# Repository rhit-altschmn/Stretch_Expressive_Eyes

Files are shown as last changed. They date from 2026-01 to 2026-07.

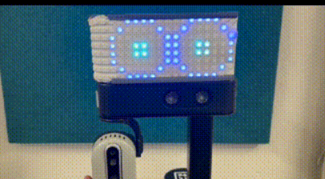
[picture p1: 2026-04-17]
Expressive_Eyes/normal eyes pic.png

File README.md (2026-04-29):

This is a custom LED eye module design for the Hello-Robo RE2. This Eye module displays different emotions (sad, angry, happy, confuse, and normal (staring)) and can gaze utilizing the tilt-pan camera located on the robot. 

Eyes_expressions gaze1-3

Eyes_expressions-3

**BOM** 

Arduino Mega or an ESP32 board

Ability to 3D print (stand)

BTF-Lighting (8cm*32cm) LED strip (link: https://a.co/d/6l0Y1tK)

**LED strip wire connections** 

Red = Vout (5V)

White = Ground 

Green = signal[data] (Pin4 in Arduino)

**How to install** 
Clone the repo into your Catkin folder.

**How to run**

1) activate the conda environment
{conda activate pickup}

2) run the Hello-Robot calibration code {stretch_robot_home.py} Remember to remove the clip!

3) Run the launch file  # If you do not need an interface comment it out in the launch file!
{roslaunch Expressive_Eyes expression.launch or roslaunch new_expressive_eyes expression.launch}

4) In a new terminal window run the serial communication (allows you to collect information from the USB port)
{rosrun rosserial_python serial_node.py /dev/ttyACM2}

*Disclaimer: The /dev/ttyACM2 corresponds to the USB port the Arduino was connected to. It might be different for you. If it does not work run **dmesg | grep tty** to figure out the TTY device *

Remember to put the clip back on before shutdown!!

**Controls**

Gaze system: 
At this stage, the Arduino should be gathering information from the camera motor. This means that as long as the code is running, the eyes will follow whenever the camera tilts or pans.

Expressions: 
Includes four expressions and a baseline mode (normal stare). To activate an expression, simply press the corresponding key.

[{H: Happy}, {O: Normal}, {N: Angry}, {B: Sad}, {C: Confused}]

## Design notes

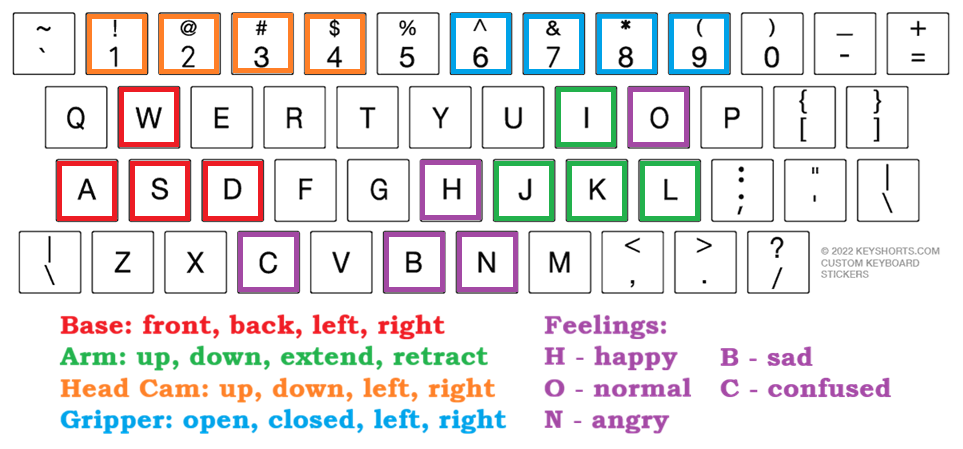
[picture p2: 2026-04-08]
Expressive_Eyes/scripts/keyboard_diagram.png

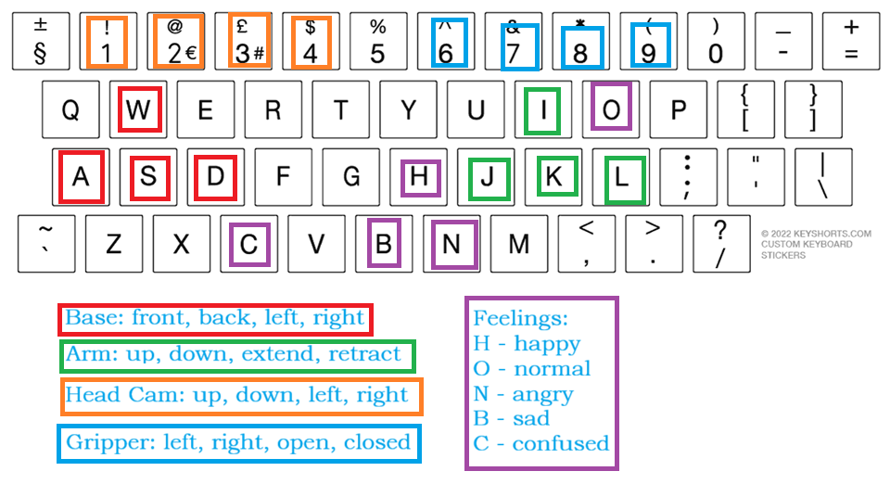
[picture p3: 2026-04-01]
Expressive_Eyes/scripts/keyboard_layout.png

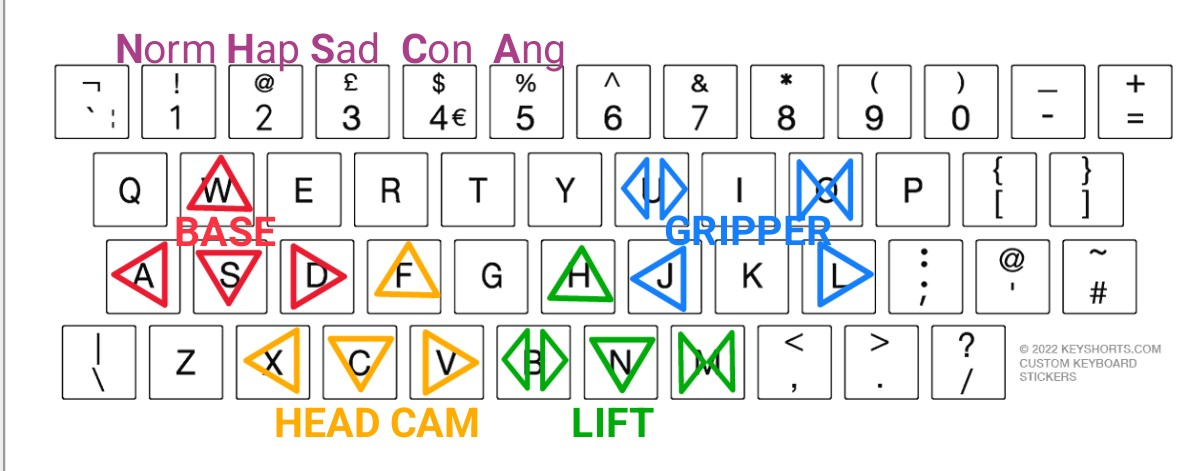
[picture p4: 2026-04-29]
Expressive_Eyes/scripts/new_keyboard_layout.png

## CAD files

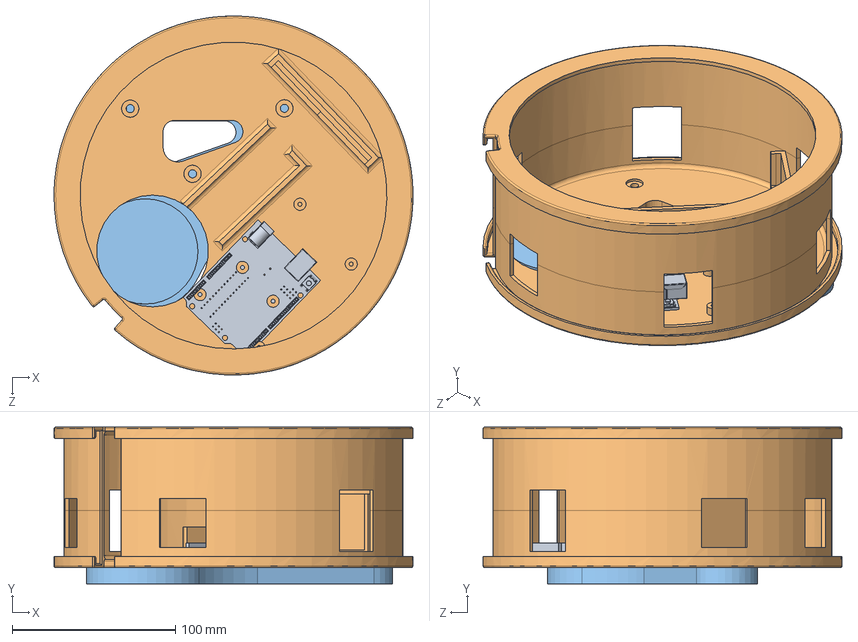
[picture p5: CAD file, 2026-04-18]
Eye_Module Stand/new_test_assembly.SLDASM
220.0 x 96.2 x 220.0 mm
Stretch_top
eye_tube_360
arduino uno

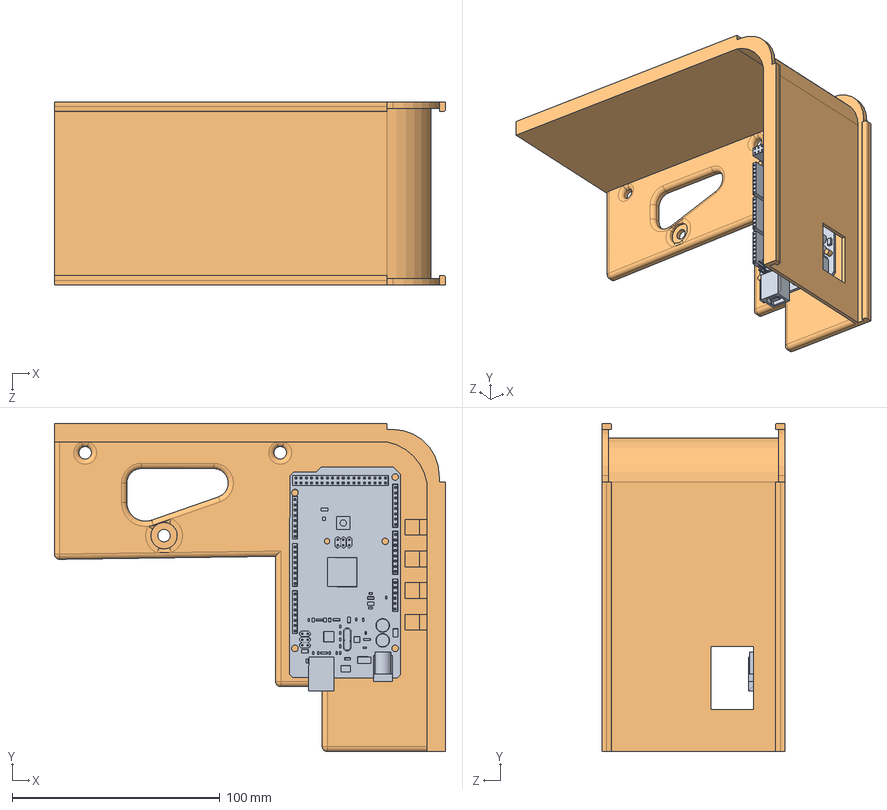
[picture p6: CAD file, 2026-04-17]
Eye_Module Stand/eyes_assem.SLDASM
188.4 x 158.2 x 88.1 mm
eye_holder (2)
ArduinoMega

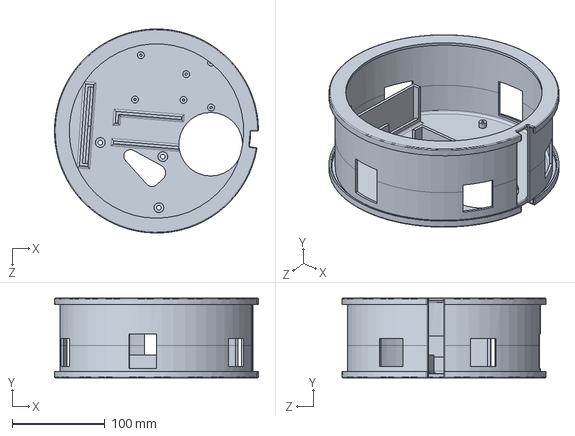
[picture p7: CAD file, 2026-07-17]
Eye_Module Stand/eye_tube_360.SLDPRT
220.0 x 86.2 x 220.0 mm

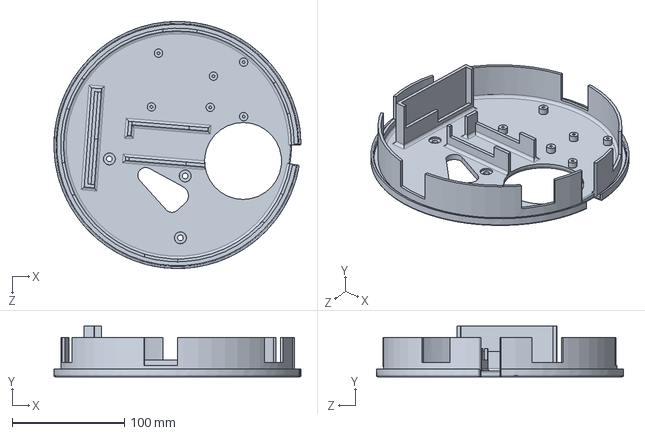
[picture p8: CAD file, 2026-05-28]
Eye_Module Stand/eye_tube_bottom_v2_final.SLDPRT
219.9 x 45.0 x 220.0 mm

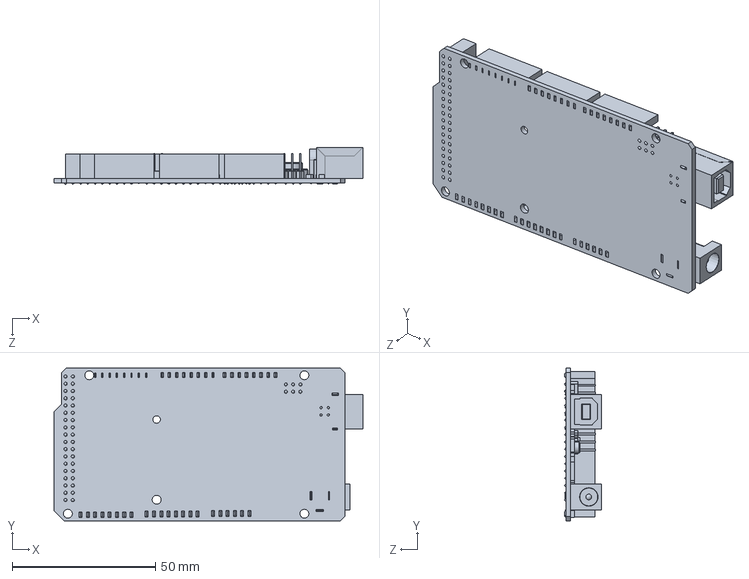
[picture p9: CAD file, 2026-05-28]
Eye_Module Stand/ArduinoMega.SLDPRT
107.9 x 53.4 x 13.0 mm

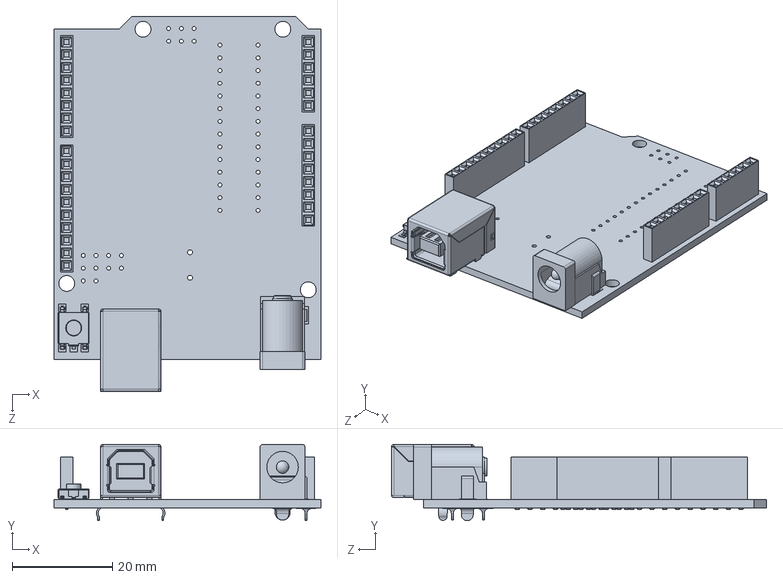
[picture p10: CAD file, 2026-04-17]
Eye_Module Stand/arduino uno.SLDPRT
53.3 x 15.2 x 74.9 mm

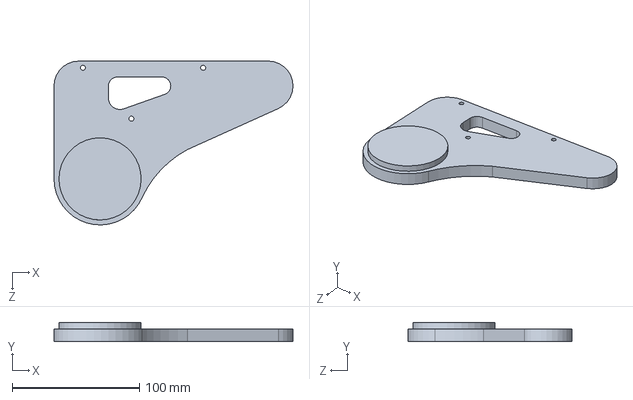
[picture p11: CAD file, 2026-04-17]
Eye_Module Stand/Stretch_top.SLDPRT
187.7 x 15.0 x 128.7 mm

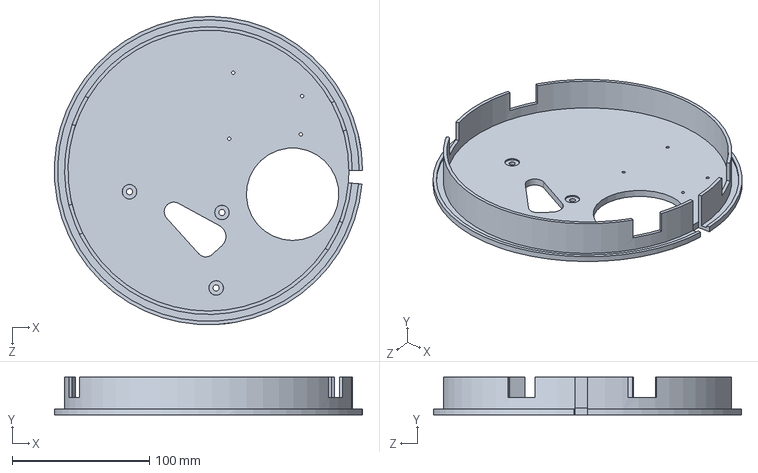
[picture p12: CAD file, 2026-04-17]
Eye_Module Stand/eye_tube_bottoms.SLDPRT
224.9 x 27.5 x 224.8 mm

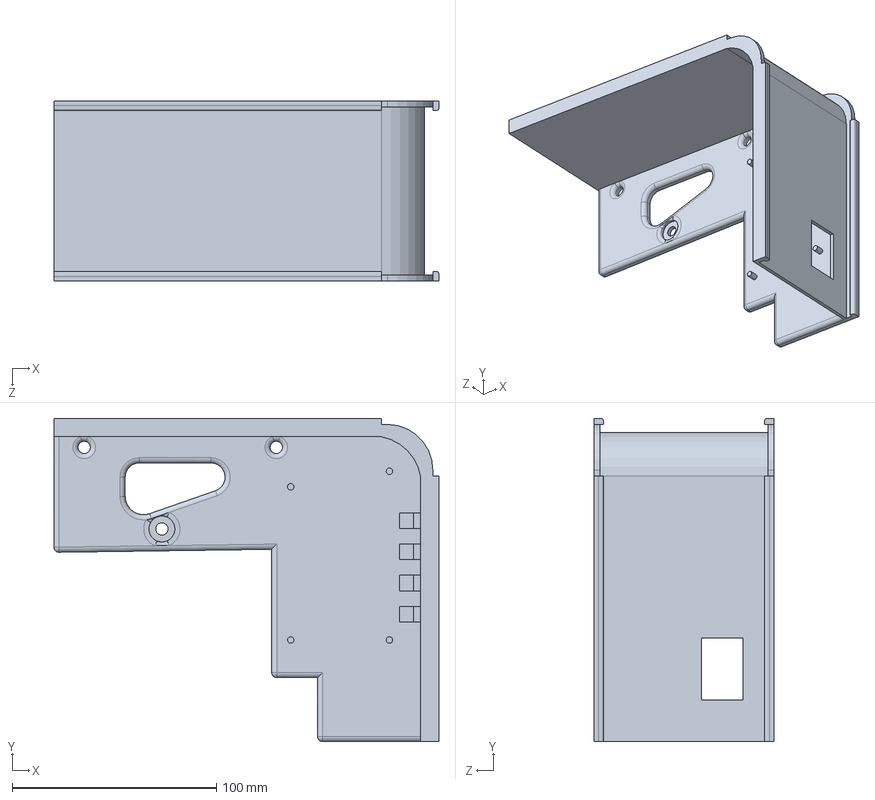
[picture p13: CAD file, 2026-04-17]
Eye_Module Stand/eye_holder (2).SLDPRT
188.4 x 158.2 x 88.1 mm

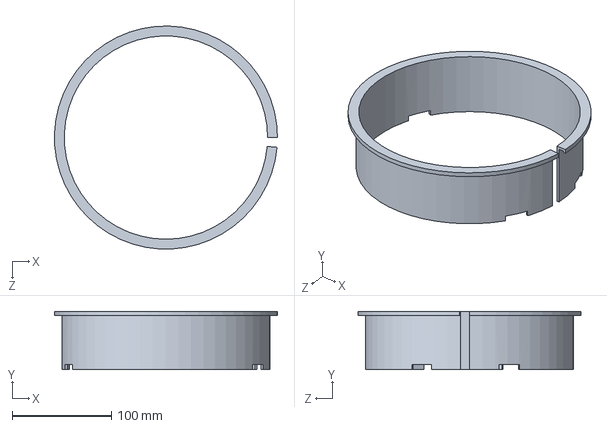
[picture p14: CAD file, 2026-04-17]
Eye_Module Stand/eye_tube_tops.SLDPRT
224.9 x 58.7 x 224.8 mm

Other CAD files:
Eye_Module Stand/eye_tube_360.STL

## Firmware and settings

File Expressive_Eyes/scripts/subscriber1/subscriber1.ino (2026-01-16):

#include <Adafruit_NeoPixel.h>
#include <ros.h>
#include <std_msgs/Float64MultiArray.h>
#include <std_msgs/String.h>

ros::NodeHandle nh;

#define PIN 4              // Arduino pin 6 to DIN of 8x32 matrix.
#define LED_COUNT 256      // 8x32 = 256 NeoPixel leds
#define BRIGHTNESS 8       // to reduce current for 256 NeoPixels

Adafruit_NeoPixel strip = Adafruit_NeoPixel(LED_COUNT, PIN, NEO_GRB + NEO_KHZ800);
bool Manip = false;
char incomingChar;
int i = 0;
int j = 0;
unsigned long previousMillis = 0;
unsigned long previousMillis2 = 0;
const long interval = 7500;
const long interval2 = 9500;
int currentExpression;
bool emote;
String emotion = "base";

float MoFlL = 0.336; //3
float MoLB = 0.026; //5 
float MoBR = -0.252; //
float MoRFr = -0.563;
float MoFr = -0.908;

float vFdD = -0.337;
float vDB = 0.001;
float vBU = 0.139;
float vUFu = 0.277;
float upper_limit = 0.415;
float lower_limit = -1.917;


float MaFlL = -1.225; //3

float MaLB = -1.542; //5 
float MaBR = -1.859; //

float MaRFr = -2.196;

float MaFr = -4.045;
float horiz;
float vert;

float transition_counter = -.130;

//////////


void camOCb(const std_msgs::Float64MultiArray & state_msg){
  horiz = state_msg.data[0];
  vert = state_msg.data[1];
}

void cam1Cb(const std_msgs::String & state_msg){
  incomingChar = state_msg.data[0];
}

ros::Subscriber<std_msgs::Float64MultiArray> sub("/head_camera_jointstate", camOCb);

ros::Subscriber<std_msgs::String> sub_1("/keyboard_input", cam1Cb);

void setup() 
{
  strip.begin();
  strip.show();            // Initialize all pixels to 'off'
  strip.setBrightness(BRIGHTNESS);   // overall brightness
  Serial.begin(57600);
  happyEyesMo();
  delay(5000);
  baseEyesMo();
  currentExpression = 1;
  nh.initNode();
  nh.subscribe(sub);
  nh.subscribe(sub_1);
}

void loop() {
  // put your main code here, to run repeatedly:

  unsigned long currentMillis = millis();
  if(currentMillis - previousMillis >= interval){
    // save last time homie blinked
    previousMillis = currentMillis;
    if(Manip == false){
      blinkEyesMo(currentExpression);      
    }
    else{
      blinkEyesMa(currentExpression);
    }
  }
  if(emotion != "base"){
    if(currentMillis - previousMillis2 >= interval2){
      previousMillis2 = currentMillis; 
      emotion = "base";     
      
    }
  }

  
//  while (Serial.available()){
//    incomingChar = Serial.read();


    switch(incomingChar) {     
      case 'h':
        emotion = "happy";
        break;
      case 'b':
        emotion = "sad";
        break;
      case 'n':
        emotion = "angry";
        break;
      case 'c':
        emotion = "confused";
        break;
      case 'o':
        emotion = "base";
        break;      
    }


// replace to original code since that has connection to the join states
// this part is what makes the eyes transition from half of the LED to the other half
    if(horiz < -0.908 && transition_counter >= -0.908){
      Manip = true;
      i += 1;
      transition_counter = horiz;
    }
    else if(horiz < -0.908 && transition_counter < -0.908){
      Manip = true;
    }
    else if(horiz >= -0.908 && transition_counter < -0.908){
      Manip = false;
      i += 1;
      transition_counter = horiz;
    }
    else if(horiz >= -0.908 && transition_counter >= -0.908){
      Manip = false;
    }

    
    if(vert >= vDB && vert < vBU && horiz <= MaLB && horiz > MaBR && Manip == true && emotion == "base"){
      if(i != j){
        mobToman();
        j = i;
      }
      baseEyesMa();
      currentExpression = 1;
     
    }  
    else if(vert >= vBU && vert < vUFu && horiz <= MaLB && horiz > MaBR && Manip == true && emotion == "base"){
      if(i != j){
        mobToman();
        j = i;
      }
      slightUpMa();
      currentExpression = 2;
    }
    else if(vert >= vUFu && vert <= upper_limit && horiz <= MaFlL && horiz > MaRFr && Manip == true && emotion == "base"){
      if(i != j){
        mobToman();
        j = i;
      }
      eyesUpMa();
      currentExpression = 3;
    } 
    else if(vert >= vFdD && vert < vDB && horiz <= MaLB && horiz > MaBR && Manip == true && emotion == "base"){
      if(i != j){
        mobToman();
        j = i;
      }
      slightDownMa();
      currentExpression = 4;
    }
    else if(vert >= lower_limit && vert < vFdD && horiz <= MaFlL && horiz > MaRFr && Manip == true && emotion == "base"){
      if(i != j){
        mobToman();
        j = i;
      }
      eyesDownMa();
      currentExpression = 5;
    }
    else if(((vert >= vFdD && vert < vDB && horiz <= MaBR && horiz > MaRFr)||(vert >= lower_limit && vert < vFdD && horiz <= MaRFr && horiz > MaFr)) && Manip == true && emotion == "base"){
      if(i != j){
        mobToman();
        j = i;
      }
      eyesDownLeftMa();
      currentExpression = 14;
    }
    else if(((vert >= vFdD && vert < vDB && horiz <= MaFlL && horiz > MaLB)||(vert >= lower_limit && vert < vFdD && horiz <= MoFr && horiz > MaFlL )) && Manip == true && emotion == "base"){
      if(i != j){
        mobToman();
        j = i;
      }
      eyesDownRightMa();
      currentExpression = 15;
    } 
    else if(((vert >= vBU && vert < vUFu && horiz <= MaBR && horiz > MaRFr)||(vert >= vUFu && vert < upper_limit && horiz <= MaRFr && horiz > MaFr )) && Manip == true && emotion == "base"){
      if(i != j){
        mobToman();
        j = i;
      }
      eyesUpLeftMa();
      currentExpression = 16;
    }
    else if(((vert >= vBU && vert < vUFu && horiz <= MaFlL && horiz > MaLB)||(vert >= vUFu && vert < upper_limit && horiz <= MoFr && horiz > MaFlL )) && Manip == true && emotion == "base"){
      if(i != j){
        mobToman();
        j = i;
      }
      eyesUpRightMa();
      currentExpression = 17;
    }    
/////////// Manipulator side ///////////////////////////
    else if(vert >= vDB && vert < vBU && horiz <= MaFlL && horiz > MaLB && Manip == true && emotion == "base"){
      if(i != j){
        mobToman();
        j = i;
      }
      slightRightMa();
      currentExpression = 6;
    }    
    else if(vert >= vFdD && vert <= vUFu && horiz >= MaFlL && horiz < MoFr && Manip == true && emotion == "base"){
      if(i != j){
        mobToman();
        j = i;
      }
      eyesRightMa();
      currentExpression = 7;
    } 
    else if(vert >= vDB && vert < vBU && horiz <= MaBR && horiz > MaRFr && Manip == true && emotion == "base"){
      if(i != j){
        mobToman();
        j = i;
      }
      slightLeftMa();
      currentExpression = 8; 
    }
    else if(vert >= vFdD && vert <= vUFu && horiz <= MaRFr && horiz > MaFr && Manip == true && emotion == "base"){
      if(i != j){
        mobToman();
        j = i;
      }
      eyesLeftMa();
      currentExpression = 9;    
    }

    if(vert >= vDB && vert < vBU && horiz <= MoLB && horiz > MoBR && Manip == false && emotion == "base"){
      if(i != j){
        manTomob();
        j = i;
      }
      baseEyesMo();
      currentExpression = 1;
     
    }  
    else if(vert >= vBU && vert < vUFu && horiz <= MoLB && horiz > MoBR && Manip == false && emotion == "base"){
      if(i != j){
        manTomob();
        j = i;
      }
      slightUpMo();
      currentExpression = 2;
    }
    else if(vert >= vUFu && vert <= upper_limit && horiz <= MoFlL && horiz > MoRFr && Manip == false && emotion == "base"){
      if(i != j){
        manTomob();
        j = i;
      }
      eyesUpMo();
      currentExpression = 3;
    } 
    else if(vert >= vFdD && vert < vDB && horiz <= MoLB && horiz > MoBR && Manip == false && emotion == "base"){
      if(i != j){
        manTomob();
        j = i;
      }
      slightDownMo();
      currentExpression = 4;
    }
    else if(vert >= lower_limit && vert < vFdD && horiz <= MoFlL && horiz > MoRFr && Manip == false && emotion == "base"){
      if(i != j){
        manTomob();
        j = i;
      }
      eyesDownMo();
      currentExpression = 5;
    } 
    else if(((vert >= vFdD && vert < vDB && horiz <= MoBR && horiz > MoRFr)||(vert >= lower_limit && vert < vFdD && horiz <= MoRFr && horiz > MoFr)) && Manip == false && emotion == "base"){
      if(i != j){
        manTomob();
        j = i;
      }
      eyesUpLeftMo();
      currentExpression = 14;
    }
    else if(((vert >= vFdD && vert < vDB && horiz <= MoFlL && horiz > MoLB)||(vert >= lower_limit && vert < vFdD && horiz >= MoFlL && horiz <= 1.67)) && Manip == false && emotion == "base"){
      if(i != j){
        manTomob();
        j = i;
      }
      eyesUpRightMo();
      currentExpression = 15;
    } 
    else if(((vert >= vBU && vert < vUFu && horiz <= MoBR && horiz > MoRFr)||(vert >= vUFu && vert < upper_limit && horiz <= MoRFr && horiz > MoFr )) && Manip == false && emotion == "base"){
      if(i != j){
        manTomob();
        j = i;
      }
      eyesDownLeftMo();
      currentExpression = 16;
    }
    else if(((vert >= vBU && vert < vUFu && horiz <= MoFlL && horiz > MoLB)||(vert >= vUFu && vert < upper_limit && horiz >= MoFlL && horiz <= 1.67 )) && Manip == false && emotion == "base"){
      if(i != j){
        manTomob();
        j = i;
      }
      eyesDownRightMo();
      currentExpression = 17;
    } 
/////////////// Front facing-eyes ///////////////////
    else if(vert >= vDB && vert < vBU && horiz <= MoFlL && horiz > MoLB && Manip == false && emotion == "base"){
      if(i != j){
        manTomob();
        j = i;
      }
      slightRightMo();
      currentExpression = 6;
    }    
    else if(vert >= vFdD && vert <= vUFu && horiz >= MoFlL && horiz <= 1.67 && Manip == false && emotion == "base"){
      if(i != j){
        manTomob();
        j = i;
      }
      eyesRightMo();
      currentExpression = 7;
    } 
    else if(vert >= vDB && vert < vBU && horiz <= MoBR && horiz > MoRFr && Manip == false && emotion == "base"){
      if(i != j){
        manTomob();
        j = i;
      }
      slightLeftMo();
      currentExpression = 8; 
    }
    else if(vert >= vFdD && vert <= vUFu && horiz <= MoRFr && horiz > MoFr && Manip == false && emotion == "base"){
      if(i != j){
        manTomob();
        j = i;
      }
      eyesLeftMo();
      currentExpression = 9;    
    }

    else if(emotion == "happy"){
      currentExpression = 10;
      if(Manip == false){
        happyEyesMo();
      }
      else if (Manip == true){
        happyEyesMa();
      }
      
    }
    else if(emotion == "sad"){
      currentExpression = 11;
      if(Manip == false){
        sadEyesMo();
      }
      else if (Manip == true){
        sadEyesMa();
      }
    }
    else if(emotion == "angry"){
      currentExpression = 12;
      if(Manip == false){
        angryEyesMo();
      }
      else if (Manip == true){
        angryEyesMa();
      }
    }
    else if(emotion == "confused"){
      currentExpression = 13;
      if(Manip == false){
        confusedEyesMo();
      }
      else if (Manip == true){
        confusedEyesMa();
      } 
    } 
//      eyesLeftMo();
//      currentExpression = 9;    
    
    nh.spinOnce();
    delay(100);
}

 


// --------------------------------------------- Manipulation Eye States ------------------------------------------
void baseEyesMa(){
  strip.clear();
  strip.setPixelColor(2, strip.Color(0, 0, 255));
  strip.setPixelColor(3, strip.Color(0, 0, 255));
  strip.setPixelColor(4, strip.Color(0, 0, 255));
  strip.setPixelColor(5, strip.Color(0, 0, 255));
  strip.setPixelColor(9, strip.Color(0, 0, 255));
  strip.setPixelColor(14, strip.Color(0, 0, 255));
  strip.setPixelColor(16, strip.Color(0, 0, 255));
  strip.setPixelColor(23, strip.Color(0, 0, 255));
  strip.setPixelColor(24, strip.Color(0, 0, 255));
  strip.setPixelColor(27, strip.Color(0, 250, 150));
  strip.setPixelColor(28, strip.Color(0, 250, 150));
  strip.setPixelColor(31, strip.Color(0, 0, 255));
  strip.setPixelColor(32, strip.Color(0, 0, 255));
  strip.setPixelColor(35, strip.Color(0, 250, 150));
  strip.setPixelColor(36, strip.Color(0, 250, 150));
  strip.setPixelColor(39, strip.Color(0, 0, 255));
  strip.setPixelColor(40, strip.Color(0, 0, 255));
  strip.setPixelColor(47, strip.Color(0, 0, 255));
  strip.setPixelColor(49, strip.Color(0, 0, 255));
  strip.setPixelColor(54, strip.Color(0, 0, 255));
  strip.setPixelColor(58, strip.Color(0, 0, 255));
  strip.setPixelColor(59, strip.Color(0, 0, 255));
  strip.setPixelColor(60, strip.Color(0, 0, 255));
  strip.setPixelColor(61, strip.Color(0, 0, 255));
  strip.setPixelColor(66, strip.Color(0, 0, 255));
  strip.setPixelColor(67, strip.Color(0, 0, 255));
  strip.setPixelColor(68, strip.Color(0, 0, 255));
  strip.setPixelColor(69, strip.Color(0, 0, 255));
  strip.setPixelColor(73, strip.Color(0, 0, 255));
  strip.setPixelColor(78, strip.Color(0, 0, 255));
  strip.setPixelColor(80, strip.Color(0, 0, 255));
  strip.setPixelColor(87, strip.Color(0, 0, 255));
  strip.setPixelColor(88, strip.Color(0, 0, 255));
  strip.setPixelColor(91, strip.Color(0, 250, 150));
  strip.setPixelColor(92, strip.Color(0, 250, 150));
  strip.setPixelColor(95, strip.Color(0, 0, 255));
  strip.setPixelColor(96, strip.Color(0, 0, 255));
  strip.setPixelColor(99, strip.Color(0, 250, 150));
  strip.setPixelColor(100, strip.Color(0, 250, 150));
  strip.setPixelColor(103, strip.Color(0, 0, 255));
  strip.setPixelColor(104, strip.Color(0, 0, 255));
  strip.setPixelColor(111, strip.Color(0, 0, 255));
  strip.setPixelColor(113, strip.Color(0, 0, 255));
  strip.setPixelColor(118, strip.Color(0, 0, 255));
  strip.setPixelColor(122, strip.Color(0, 0, 255));
  strip.setPixelColor(123, strip.Color(0, 0, 255));
  strip.setPixelColor(124, strip.Color(0, 0, 255));
  strip.setPixelColor(125, strip.Color(0, 0, 255));
  strip.show(); 
}
void confusedEyesMa(){
  strip.clear();
  strip.setPixelColor(4, strip.Color(0, 0, 255));
  strip.setPixelColor(10, strip.Color(0, 0, 255));
  strip.setPixelColor(12, strip.Color(0, 0, 255));
  strip.setPixelColor(18, strip.Color(0, 0, 255));
  strip.setPixelColor(22, strip.Color(0, 0, 255));
  strip.setPixelColor(25, strip.Color(0, 0, 255));
  strip.setPixelColor(29, strip.Color(0, 0, 255));
  strip.setPixelColor(34, strip.Color(0, 0, 255));
  strip.setPixelColor(38, strip.Color(0, 0, 255));
  strip.setPixelColor(36, strip.Color(0, 250, 150));
  //strip.setPixelColor(35, strip.Color(0, 250, 150));
  strip.setPixelColor(41, strip.Color(0, 0, 255));
  strip.setPixelColor(45, strip.Color(0, 0, 255));
  //strip.setPixelColor(44, strip.Color(0, 250, 150));
  strip.setPixelColor(43, strip.Color(0, 250, 150));
  strip.setPixelColor(50, strip.Color(0, 0, 255));
  strip.setPixelColor(54, strip.Color(0, 0, 255));
  strip.setPixelColor(57, strip.Color(0, 0, 255));
  strip.setPixelColor(61, strip.Color(0, 0, 255));
  strip.setPixelColor(67, strip.Color(0, 0, 255));
  strip.setPixelColor(69, strip.Color(0, 0, 255));
  strip.setPixelColor(75, strip.Color(0, 0, 255));
  strip.setPixelColor(90, strip.Color(0, 0, 255));
  strip.setPixelColor(91, strip.Color(0, 0, 255));
  strip.setPixelColor(92, strip.Color(0, 0, 255));
  strip.setPixelColor(93, strip.Color(0, 0, 255));
  strip.setPixelColor(97, strip.Color(0, 0, 255));
  strip.setPixelColor(102, strip.Color(0, 0, 255));
  strip.setPixelColor(104, strip.Color(0, 0, 255));
  strip.setPixelColor(111, strip.Color(0, 0, 255));
  strip.setPixelColor(113, strip.Color(0, 0, 255));
  strip.setPixelColor(118, strip.Color(0, 0, 255));
  strip.setPixelColor(122, strip.Color(0, 0, 255));
  strip.setPixelColor(123, strip.Color(0, 0, 255));
  //strip.setPixelColor(99, strip.Color(0, 250, 150));
  //strip.setPixelColor(100, strip.Color(0, 250, 150));
  strip.setPixelColor(124, strip.Color(0, 0, 255));
  strip.setPixelColor(125, strip.Color(0, 0, 255));
  strip.setPixelColor(107, strip.Color(0, 250, 150));
  strip.setPixelColor(108, strip.Color(0, 250, 150));
//  strip.setPixelColor(111, strip.Color(0, 0, 255));
//  strip.setPixelColor(113, strip.Color(0, 0, 255));
//  strip.setPixelColor(118, strip.Color(0, 0, 255));
//  strip.setPixelColor(117, strip.Color(0, 0, 255));
//  strip.setPixelColor(116, strip.Color(0, 0, 255));
//  strip.setPixelColor(115, strip.Color(0, 0, 255));
//  strip.setPixelColor(114, strip.Color(0, 0, 255));
  //strip.setPixelColor(124, strip.Color(0, 0, 255));
  //strip.setPixelColor(125, strip.Color(0, 0, 255));
  strip.show(); 
}
void angryEyesMa(){
  strip.clear();
  strip.setPixelColor(2, strip.Color(0, 0, 255));
  strip.setPixelColor(3, strip.Color(0, 0, 255));
  strip.setPixelColor(4, strip.Color(0, 0, 255));
  strip.setPixelColor(5, strip.Color(0, 0, 255));
  strip.setPixelColor(9, strip.Color(0, 0, 255));
  strip.setPixelColor(14, strip.Color(0, 0, 255));
  strip.setPixelColor(17, strip.Color(0, 0, 255));
  strip.setPixelColor(23, strip.Color(0, 0, 255));
  strip.setPixelColor(24, strip.Color(0, 0, 255));
  strip.setPixelColor(26, strip.Color(0, 250, 150));
  strip.setPixelColor(27, strip.Color(0, 250, 150));
  strip.setPixelColor(30, strip.Color(0, 0, 255));
  strip.setPixelColor(34, strip.Color(0, 0, 255));
  strip.setPixelColor(37, strip.Color(0, 250, 150));
  strip.setPixelColor(36, strip.Color(0, 250, 150));
  strip.setPixelColor(39, strip.Color(0, 0, 255));
  strip.setPixelColor(40, strip.Color(0, 0, 255));
  strip.setPixelColor(44, strip.Color(0, 0, 255));
  strip.setPixelColor(52, strip.Color(0, 0, 255));
  strip.setPixelColor(55, strip.Color(0, 0, 255));
  strip.setPixelColor(56, strip.Color(0, 0, 255));
  strip.setPixelColor(57, strip.Color(0, 0, 255));
  strip.setPixelColor(58, strip.Color(0, 0, 255));
  //strip.setPixelColor(60, strip.Color(0, 0, 255));
  //strip.setPixelColor(61, strip.Color(0, 0, 255));
  //strip.setPixelColor(66, strip.Color(0, 0, 255));
  //strip.setPixelColor(67, strip.Color(0, 0, 255));
  strip.setPixelColor(69, strip.Color(0, 0, 255));
  strip.setPixelColor(70, strip.Color(0, 0, 255));
  strip.setPixelColor(71, strip.Color(0, 0, 255));
  strip.setPixelColor(72, strip.Color(0, 0, 255));
  strip.setPixelColor(75, strip.Color(0, 0, 255));  
  strip.setPixelColor(83, strip.Color(0, 0, 255));
  strip.setPixelColor(87, strip.Color(0, 0, 255));
  strip.setPixelColor(88, strip.Color(0, 0, 255));
  strip.setPixelColor(91, strip.Color(0, 250, 150));
  strip.setPixelColor(90, strip.Color(0, 250, 150));
  strip.setPixelColor(93, strip.Color(0, 0, 255));
  strip.setPixelColor(97, strip.Color(0, 0, 255));
  strip.setPixelColor(100, strip.Color(0, 250, 150));
  strip.setPixelColor(101, strip.Color(0, 250, 150));
  strip.setPixelColor(103, strip.Color(0, 0, 255));
  strip.setPixelColor(104, strip.Color(0, 0, 255));
  strip.setPixelColor(110, strip.Color(0, 0, 255));
  strip.setPixelColor(113, strip.Color(0, 0, 255));
  strip.setPixelColor(118, strip.Color(0, 0, 255));
  strip.setPixelColor(122, strip.Color(0, 0, 255));
  strip.setPixelColor(123, strip.Color(0, 0, 255));
  strip.setPixelColor(124, strip.Color(0, 0, 255));
  strip.setPixelColor(125, strip.Color(0, 0, 255));
//  strip.setPixelColor(67, strip.Color(50, 0, 155));
//  strip.setPixelColor(31, strip.Color(50, 0, 155));
//  strip.setPixelColor(32, strip.Color(50, 0, 155));
//  strip.setPixelColor(46, strip.Color(50, 0, 155));
//  strip.setPixelColor(50, strip.Color(50, 0, 155));
//  strip.setPixelColor(60, strip.Color(50, 0, 155));
//  strip.setPixelColor(96, strip.Color(50, 0, 155));
//  strip.setPixelColor(95, strip.Color(50, 0, 155));
//  strip.setPixelColor(81, strip.Color(50, 0, 155));
//  strip.setPixelColor(77, strip.Color(50, 0, 155));
  strip.show(); 
}
void sadEyesMa(){
  strip.clear();
  strip.setPixelColor(57, strip.Color(0, 0, 255));
  strip.setPixelColor(5, strip.Color(0, 0, 255));
  strip.setPixelColor(6, strip.Color(0, 0, 255));
  strip.setPixelColor(8, strip.Color(0, 0, 255));
  strip.setPixelColor(11, strip.Color(0, 0, 255));
  strip.setPixelColor(29, strip.Color(0, 0, 255));
  strip.setPixelColor(23, strip.Color(0, 0, 255)); 
  strip.setPixelColor(24, strip.Color(0, 0, 255));
  strip.setPixelColor(42, strip.Color(0, 250, 150));
  strip.setPixelColor(41, strip.Color(0, 250, 150));
  strip.setPixelColor(19, strip.Color(0, 0, 255));
  strip.setPixelColor(33, strip.Color(0, 0, 255));
  strip.setPixelColor(37, strip.Color(0, 250, 150));
  strip.setPixelColor(38, strip.Color(0, 250, 150));
  strip.setPixelColor(39, strip.Color(0, 0, 255));
  strip.setPixelColor(40, strip.Color(0, 0, 255));
  strip.setPixelColor(46, strip.Color(0, 0, 255));
  strip.setPixelColor(49, strip.Color(0, 0, 255));
  strip.setPixelColor(55, strip.Color(0, 0, 255));
  strip.setPixelColor(58, strip.Color(0, 0, 255));
  strip.setPixelColor(59, strip.Color(0, 0, 255));
  strip.setPixelColor(60, strip.Color(0, 0, 255));
  strip.setPixelColor(61, strip.Color(0, 0, 255));
  strip.setPixelColor(66, strip.Color(0, 0, 255));
  strip.setPixelColor(67, strip.Color(0, 0, 255));
  strip.setPixelColor(68, strip.Color(0, 0, 255));
  strip.setPixelColor(69, strip.Color(0, 0, 255));  
  strip.setPixelColor(70, strip.Color(0, 0, 255));
  strip.setPixelColor(72, strip.Color(0, 0, 255));
  strip.setPixelColor(78, strip.Color(0, 0, 255));
  strip.setPixelColor(81, strip.Color(0, 0, 255));
  strip.setPixelColor(87, strip.Color(0, 0, 255));
  strip.setPixelColor(88, strip.Color(0, 0, 255));  
  strip.setPixelColor(89, strip.Color(0, 250, 150));
  strip.setPixelColor(90, strip.Color(0, 250, 150));
  strip.setPixelColor(94, strip.Color(0, 0, 255));
  strip.setPixelColor(108, strip.Color(0, 0, 255));
  strip.setPixelColor(85, strip.Color(0, 250, 150));
  strip.setPixelColor(86, strip.Color(0, 250, 150));
  strip.setPixelColor(103, strip.Color(0, 0, 255));
  strip.setPixelColor(104, strip.Color(0, 0, 255));
  strip.setPixelColor(98, strip.Color(0, 0, 255));
  strip.setPixelColor(116, strip.Color(0, 0, 255));
  strip.setPixelColor(119, strip.Color(0, 0, 255));
  strip.setPixelColor(122, strip.Color(0, 0, 255));
  strip.setPixelColor(121, strip.Color(0, 0, 255));
  strip.show(); 
}
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

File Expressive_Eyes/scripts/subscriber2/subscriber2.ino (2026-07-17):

#include <Adafruit_NeoPixel.h>
#include <ros.h>
#include <std_msgs/Float64MultiArray.h>
#include <std_msgs/String.h>


ros::NodeHandle nh;

#define PIN 4              // Arduino pin 6 to DIN of 8x32 matrix.
#define LED_COUNT 256*2      // 8x32 = 256 NeoPixel leds
#define BRIGHTNESS 8       // to reduce current for 256 NeoPixels

Adafruit_NeoPixel strip = Adafruit_NeoPixel(LED_COUNT, PIN, NEO_GRB + NEO_KHZ800);
bool Manip = false;
char incomingChar;
// int i = 0;
// int j = 0;
unsigned long previousMillis = 0;
unsigned long previousMillis2 = 0;
const long interval = 5000;   //7500
const long interval2 = 9500;
int currentExpression;
// bool emote;
String emotion = "base";

float vFdD = -0.337;
float vDB = 0.001;
float vBU = 0.139;
float vUFu = 0.277;
float upper_limit = 0.415;
float lower_limit = -1.917;

float horiz;
float vert;

float eye_edges[6] = {-2.75,-1.96,-1.18,-0.4,	0.4,1.18};   //{1.178097245,	0.3926990817,	-0.3926990817,	-1.178097245,	-1.963495408,	-2.748893572}
float pupil_edges[4] = {-0.337,0.001,0.139,0.277};

int sq_corner[8] = {0,64,64*2,64*3,64*4,64*5,64*6,64*7};
int eye_pos_index;
int pupil_loc;

//eye emotions
int baseEyeNums[20] = {2,3,4,5,9,14,16,23,24,31,32,39,40,47,49,54,58,59,60,61};
int closedEyeNums[6] = {11,21,25,38,42,52};

int happyEyeNums[6] = {12,18,30,33,45,51};
int confusedLeftNums[15] = {4, 10, 12, 18, 29, 34, 45, 50, 61, 22, 25, 38, 41, 54, 57};
int confusedLeftPupil[2] = {36, 43};
int confusedRightNums[17] = {3, 5, 11, 26, 27, 28, 28, 33, 47, 49, 61, 60, 59, 58, 54, 40, 38};
int confusedRightPupil[2] = {43,44};

// pupils
int centerPupils[4] = {27,28,35,36};
int slightUpPupils[4] = {28,29,34,35};
int upPupils[4] = {29,30,33,34};
int slightDownPupils[4] = {26,27,36,37};
int downPupils[4] = {25,26,37,38};

uint8_t eyeLineColor[3] = {0,0,255};
uint8_t eyePupilColor[3] = {0,250,150};



void camOCb(const std_msgs::Float64MultiArray & state_msg){  //eye info
  horiz = state_msg.data[0];
  vert = state_msg.data[1];
}

void cam1Cb(const std_msgs::String & state_msg){ //keyboard input
  incomingChar = state_msg.data[0];
}

ros::Subscriber<std_msgs::Float64MultiArray> sub("/head_camera_jointstate", camOCb);

ros::Subscriber<std_msgs::String> sub_1("/keyboard_input", cam1Cb);

void setup() {
  strip.begin();
  strip.show();            // Initialize all pixels to 'off'
  strip.setBrightness(BRIGHTNESS);   // overall brightness
  Serial.begin(57600);
  happyEyes(0);
  delay(5000);
  baseEyes(0,0);
  currentExpression = 1;

  eye_pos_index = 0;
  pupil_loc = 0;
  nh.initNode();
  nh.subscribe(sub);
  nh.subscribe(sub_1);
}


void loop() {
  // put your main code here, to run repeatedly:
  unsigned long currentMillis = millis();
  eye_pos_index = camPanMap(horiz);
  pupil_loc = camTiltMap(vert);

  if (emotion == "base"){
    baseEyes(eye_pos_index,pupil_loc);
    if(currentMillis - previousMillis >= interval){
      // save last time homie blinked
      previousMillis = currentMillis;
      
      closedEyes(eye_pos_index);
      delay(200); //150
      baseEyes(eye_pos_index,pupil_loc);
    }
  }
  
  else{
    
    // switch(emotion){
    //   case "happy":
    //     happyEyes(eye_pos_index);
    //     break;
    //   case "confused":
    //     confusedEyes(eye_pos_index);
    //     break;



    // }

    if (emotion == "happy"){
      happyEyes(eye_pos_index);
    }
    if (emotion == "confused"){
      confusedEyes(eye_pos_index);
    }

    if(currentMillis - previousMillis2 >= interval2){
      previousMillis2 = currentMillis; 
      emotion = "base";     
      
    }
  }

  // if (Serial.available() > 0) {
  //   char incomingByte = Serial.read();
  //   Serial.print("I received: ");
  //   Serial.println(incomingByte);
  // }

  // while (Serial.available()){
  //   char incomingChar = Serial.read();
    // Serial.print("I received: ");
    // Serial.println(incomingChar);

  switch(incomingChar) {     
    case '2':
      emotion = "happy";
      // Serial.println("set emotion happy");
      break;
    case '3':
      emotion = "sad";
      break;
    case '4':
      emotion = "confused";
      break;
    case '5':
      emotion = "angry";
      break;
    case '1':
      emotion = "base";
      // Serial.println("set emotion base");
      break;      
  }

  // }

  nh.spinOnce();
  delay(100);

}



//------ Eyes  ------

void baseEyes(int eye_index, int pupils){
  strip.clear();

  for (int n = 0; n < 20; n++){
    strip.setPixelColor(sq_corner[eye_index] + baseEyeNums[n], eyeLineColor[0],eyeLineColor[1],eyeLineColor[2]);
    strip.setPixelColor(sq_corner[eye_index+1] + baseEyeNums[n], eyeLineColor[0],eyeLineColor[1],eyeLineColor[2]);
  }

  drawPupils(eye_index,pupils);
  strip.show();

}

void closedEyes(int eye_index){
  strip.clear();

  for (int n = 0; n < 6; n++){
    strip.setPixelColor(sq_corner[eye_index] + closedEyeNums[n], eyeLineColor[0],eyeLineColor[1],eyeLineColor[2]);
    strip.setPixelColor(sq_corner[eye_index+1] + closedEyeNums[n], eyeLineColor[0],eyeLineColor[1],eyeLineColor[2]);
  }
  strip.show();
}

void happyEyes(int eye_index){
  strip.clear();

  for (int n = 0; n < 6; n++){
    strip.setPixelColor(sq_corner[eye_index] + happyEyeNums[n], eyeLineColor[0],eyeLineColor[1],eyeLineColor[2]);
    strip.setPixelColor(sq_corner[eye_index+1] + happyEyeNums[n], eyeLineColor[0],eyeLineColor[1],eyeLineColor[2]);
  }
  strip.show();
}

void confusedEyes(int eye_index){
  strip.clear();

  for (int n = 0; n < 15; n++){
    strip.setPixelColor(sq_corner[eye_index] + confusedLeftNums[n], eyeLineColor[0],eyeLineColor[1],eyeLineColor[2]);
  }
  for (int n = 0; n < 17; n++){
    strip.setPixelColor(sq_corner[eye_index+1] + confusedRightNums[n], eyeLineColor[0],eyeLineColor[1],eyeLineColor[2]);
  }

  for (int m = 0; m < 2; m++){
    strip.setPixelColor(sq_corner[eye_index] + confusedLeftPupil[m], eyePupilColor[0],eyePupilColor[1],eyePupilColor[2]);
    strip.setPixelColor(sq_corner[eye_index+1] + confusedRightPupil[m], eyePupilColor[0],eyePupilColor[1],eyePupilColor[2]);
  }
  
  strip.show();
}
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

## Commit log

2026-04-17 new 360 eyes
    [Stretch_top.SLDPRT, arduino uno.SLDPRT, eye_holder (2).SLDPRT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]
2026-04-18 cam control for pupils and eyes
    [new_test_assembly.SLDASM]
2026-05-28 begin hotkey, update keyboard node, new arduino
    [ArduinoMega.SLDPRT, bottom_v2_test2.SLDPRT, bottom_v2_test2.STL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]
2026-05-28 Revert "begin hotkey, update keyboard node, new arduino"
    This reverts commit 59e3fa675ab42dfe42f6cae8ee79bb5ea7ba7c9a.
    [ArduinoMega.SLDPRT, bottom_v2_test2.SLDPRT, bottom_v2_test2.STL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]
2026-05-28 new eyes and test hotkeys
    [eye_tube_360.SLDPRT, eye_tube_bottom_v2_final.SLDPRT]
2026-07-17 add .gitignore and final push to main
    [eye_tube_360.SLDPRT]
